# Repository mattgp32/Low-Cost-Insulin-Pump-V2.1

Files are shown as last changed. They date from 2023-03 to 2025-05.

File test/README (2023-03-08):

This directory is intended for PlatformIO Test Runner and project tests.

Unit Testing is a software testing method by which individual units of
source code, sets of one or more MCU program modules together with associated
control data, usage procedures, and operating procedures, are tested to
determine whether they are fit for use. Unit testing finds problems early
in the development cycle.

More information about PlatformIO Unit Testing:
- https://docs.platformio.org/en/latest/advanced/unit-testing/index.html

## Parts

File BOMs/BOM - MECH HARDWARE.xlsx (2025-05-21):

Value | Qty | Material | Unit Cost (USD) | Total Cost (USD) | Supplier
Lid | 1 | SLA (9600 Resin) | $1.0500 | $1.0500 | Digikey
Case | 1 | SLA (9600 Resin) | $0.3600 | $0.3600 | Digikey
Plunger | 1 | FDM (PLA) | $3.0000 | $3.0000 | Digikey
Threaded Insert | 1 | Aluminium | $0.0900 | $0.0900 | RS Components
M2 Bolt 20mm (for case) | 2 | Stainless Steel | $0.1000 | $0.2000 | Mecha4Makers
M2 Bolt 18mm (for PCB) | 1 | Aluminium | $0.1000 | $0.1000 | RS Components
 |  |  | TOTAL | $4.8000

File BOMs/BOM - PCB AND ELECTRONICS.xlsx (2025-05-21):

Reference | Value | Footprint | Qty | Unit Cost (USD) | Total Cost (USD) | Supplier | Supplier Part No.
BZ1 | Buzzer | Bluetooth Pump V2:ST-0503 BUZZER | 1 | $2.7900 | $2.7900 | Digikey | 433-1083-6-ND
C1 | 22uF | Capacitor_SMD:C_0402_1005Metric | 1 | $0.0800 | $0.0800 | Digikey | 587-1452-6-ND
C2,C4,C5,C13,C19 | 1uF | Capacitor_SMD:C_0402_1005Metric | 5 | $0.0800 | $0.4000 | Digikey | 587-1231-6-ND
C3,C9,C12,C20,C21,C22 | 100nF | Capacitor_SMD:C_0402_1005Metric | 6 | $0.1000 | $0.6000 | Digikey | 1276-CL05B104KP5VPNCDKR-ND
C6,C7 | 12pF | Capacitor_SMD:C_0402_1005Metric | 2 | $0.1500 | $0.3000 | Digikey | 490-11190-6-ND
C8 | 2.2uF | Capacitor_SMD:C_0402_1005Metric | 1 | $0.0800 | $0.0800 | Digikey | 1276-1469-6-ND
C10,C14,C15,C16,C24 | 10uF | Capacitor_SMD:C_0402_1005Metric | 5 | $0.0800 | $0.4000 | Digikey | 1276-1450-6-ND
C11,C28 | 100uF | Capacitor_SMD:C_1210_3225Metric | 2 | $0.5700 | $1.1400 | Digikey | 490-10530-6-ND
C17,C18 | 4.7uF | Capacitor_SMD:C_0402_1005Metric | 2 | $0.0800 | $0.1600 | Digikey | 1276-1481-6-ND
C25,C26,C27 | 10nF | Capacitor_SMD:C_0402_1005Metric | 3 | $0.1000 | $0.3000 | Digikey | 399-C0402C103K4REC7411DKR-ND
D1 | SD103AWS | Diode_SMD:D_SOD-323 | 1 | $0.1100 | $0.1100 | Digikey | 4530-SD103AWSDKR-ND
D2 | LED Green | LED_SMD:LED_0603_1608Metric | 1 | $0.1500 | $0.1500 | Digikey | 732-4980-6-ND
D3 | LED Red | LED_SMD:LED_0603_1608Metric | 1 | $0.1500 | $0.1500 | Digikey | 732-4978-6-ND
D5,D6,D7 | LED Blue | LED_SMD:LED_0603_1608Metric | 3 | $0.1500 | $0.4500 | Digikey | 732-4966-6-ND
FB1 | Ferrite Bead | Inductor_SMD:L_0402_1005Metric | 1 | $0.1600 | $0.1600 | Digikey | 3442-MZAH1005F101-1R1TFDKR-ND
J4 | GCT USB4085 | Connector_USB:USB_C_Receptacle_GCT_USB4085 | 1 | $0.8800 | $0.8800 | Digikey | 2073-USB4085-GF-ADKR-ND
J5 | Molex | Connector_Hirose:Hirose_DF13-04P-1.25DSA_1x04_P1.25mm_Vertical | 1 | $0.2700 | $0.2700 | Digikey | WM1733-ND
J6 | Conn_01x02 | Connector_PinHeader_1.27mm:PinHeader_1x02_P1.27mm_Vertical | 1 | $0.3900 | $0.3900 | Digikey | 455-1788-6-ND
J8,J9 | Thermistor | Connector_PinHeader_1.27mm:PinHeader_1x02_P1.27mm_Vertical | 2 | $0.5300 | $1.0600 | Digikey | 5666-103JG1J-ND
L1 | 4.7 uH | Inductor_SMD:L_1008_2520Metric | 1 | $0.1600 | $0.1600 | Digikey | 587-3228-6-ND
Q2 | MMBT2222A | Package_TO_SOT_SMD:SOT-23 | 1 | $0.4600 | $0.4600 | Digikey | 846-DTD543EE3TLDKR-ND
R1,R2,R8,R9,R10,R13,R21,R22,R29,R31 | 10K | Resistor_SMD:R_0402_1005Metric | 10 | $0.0390 | $0.3900 | Digikey | 1276-3431-6-ND
R3 | 180R | Resistor_SMD:R_0402_1005Metric | 1 | $0.1000 | $0.1000 | Digikey | A129618DKR-ND
R4,R5 | 0R | Resistor_SMD:R_0402_1005Metric | 2 | $0.1000 | $0.2000 | Digikey | P0.0JDKR-ND
R6,R7 | 5.11k | Resistor_SMD:R_0402_1005Metric | 2 | $0.1000 | $0.2000 | Digikey | 311-5.11KLRDKR-ND
R11,R12 | 500m | Resistor_SMD:R_0402_1005Metric | 2 | $0.2800 | $0.5600 | Digikey | 13-PT0402FR-070R5LDKR-ND
R16 | 130R | Resistor_SMD:R_0402_1005Metric | 1 | $0.1000 | $0.1000 | Digikey | RMCF0402FT130RDKR-ND
R17 | 1.43M | Resistor_SMD:R_0402_1005Metric | 1 | $0.1000 | $0.1000 | Digikey | 13-RC0402FR-071M43LDKR-ND
R18 | 360k | Resistor_SMD:R_0402_1005Metric | 1 | $0.1000 | $0.1000 | Digikey | 311-360KLRDKR-ND
R19 | 150R | Resistor_SMD:R_0402_1005Metric | 1 | $0.1000 | $0.1000 | Digikey | 311-150LRDKR-ND
R20 | 5K6 | Resistor_SMD:R_0402_1005Metric | 1 | $0.1000 | $0.1000 | Digikey | 311-5.6KLRDKR-ND
R24,R25 | 100K | Resistor_SMD:R_0402_1005Metric | 2 | $0.1000 | $0.2000 | Digikey | 311-100KJRDKR-ND
R26,R27,R28 | 50R | Resistor_SMD:R_0402_1005Metric | 3 | $0.1800 | $0.5400 | Digikey | 13-RT0402BRE0750RLDKR-ND
SW1 | RESET | Button_Switch_SMD:SW_DIP_SPSTx01_Slide_6.7x4.1mm_W6.73mm_P2.54mm_LowProfile_JPin | 1 | $0.2400 | $0.2400 | Digikey | CKN12330-6-ND
SW2 | BOOT | Button_Switch_SMD:SW_DIP_SPSTx01_Slide_6.7x4.1mm_W6.73mm_P2.54mm_LowProfile_JPin | 1 | $0.2400 | $0.2400 | Digikey | CKN12330-6-ND
SW3 | WIFI | Button_Switch_SMD:SW_DIP_SPSTx01_Slide_6.7x4.1mm_W6.73mm_P2.54mm_LowProfile_JPin | 1 | $0.2400 | $0.2400 | Digikey | CKN12330-6-ND
U1 | ESP32-S3-WROOM-1-N16R2 | GlucoseWatchFootprints:ESP32-S3-WROOM-1 | 1 | $6.1300 | $6.1300 | Digikey | 5407-ESP32-S3-WROOM-1-N16R2DKR-ND
U2 | RCLAMP1624T.TCT | GlucoseWatchFootprints:SLP1710P4T | 1 | $1.6800 | $1.6800 | Digikey | RCLAMP1624TTCTDKR-ND
U3 | DRV8846RGET | DRV8846RGET:QFN50P400X400X100-25N | 1 | $2.6600 | $2.6600 | Digikey | 296-40083-6-ND
U4 | ~ | Bluetooth Pump V2:DPAK | 1 | $0.9400 | $0.9400 | Digikey | AP7363-33D-13DKR-ND
U5 | MCP16414T-IMN | SOP50P490X110-10N:SOP50P490X110-10N | 1 | $0.8500 | $0.8500 | Digikey | 150-MCP16414T-I/UNDKR-ND
U6 | MCP73831-2-OT | Package_TO_SOT_SMD:SOT-23-5 | 1 | $0.7600 | $0.7600 | Digikey | MCP73831T-2DCI/OTDKR-ND
Y1 | FC-135_32.7680KA-A0 | FC-135_32.7680KA-A0:XTAL_FC-135_32.7680KA-A0 | 1 | $1.2400 | $1.2400 | Digikey | 535-13425-6-ND
Battery Connector | 02SR-3S | N/A | 1 | $0.2300 | $0.2300 | Digikey | 455-2183-ND
Slide Potentiometer | PTL20-15G1-203B2 | N/A | 1 | $2.4600 | $2.4600 | Digikey | PTL20-15G1-203B2-ND
Stepper Motor | CHS-GM12-10BY (Ratio 298:1, M4*55mm) | N/A | 1 | $9.9000 | $9.9000 | Alibaba | ChiHai Motor CHS-GM12-10BY
PCB Manufacture | JLCPCB | N/A | 1 | $0.7000 | $0.7000 | JLCPCB | N/A
LiPo-Battery | Emax 1S 3.8V 450mAh 80/160c HV | N/A | 1 | $8.3600 | $8.3600 | Hobby Station NZ | 1s45080c
 |  |  |  | TOTAL | $49.8100

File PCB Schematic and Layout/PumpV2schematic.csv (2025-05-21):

Reference | Value | Footprint | Datasheet | Qty | DNP | Exclude from BOM | Exclude from Board
5V1,BATT1,VBUS1 | TestPoint | TestPoint:TestPoint_Pad_1.0x1.0mm | ~ | 3
A1,A2,A3 | A0 | TestPoint:TestPoint_THTPad_1.0x1.0mm_Drill0.5mm | ~ | 3 |  | Excluded from BOM
BZ1 | Buzzer | Bluetooth Pump V2:ST-0503 BUZZER | ~ | 1
C1 | 22u | Capacitor_SMD:C_0402_1005Metric | https://www.digikey.co.nz/en/products/detail/samsung-electro-mechanics/CL05A226MQ5N6J8/7320595 | 1
C2,C4,C5,C13,C19 | 1uF | Capacitor_SMD:C_0402_1005Metric | https://www.digikey.co.nz/en/products/detail/tdk-corporation/C1005X5R1E105K050BC/3648556 | 5
C3,C9,C12,C20,C21,C22 | 100nF | Capacitor_SMD:C_0402_1005Metric | https://www.digikey.co.nz/en/products/detail/murata-electronics/GRM155C71H104JE19D/8323490,~ | 6
C6,C7 | 12pF | Capacitor_SMD:C_0402_1005Metric | ~ | 2
C8 | 2.2uF | Capacitor_SMD:C_0402_1005Metric | ~ | 1
C10,C14,C15,C16,C24 | 10uF | Capacitor_SMD:C_0402_1005Metric | ~ | 5
C11,C28 | 100uF | Capacitor_SMD:C_1210_3225Metric | ~ | 2
C17,C18 | 4.7uF | Capacitor_SMD:C_0402_1005Metric | ~ | 2
C25,C26,C27 | 10nF | Capacitor_SMD:C_0402_1005Metric | ~ | 3
D1 | SD103AWS | Diode_SMD:D_SOD-323 | ~ | 1
D2 | LED Green | LED_SMD:LED_0603_1608Metric | ~ | 1
D3 | LED Red | LED_SMD:LED_0603_1608Metric | ~ | 1
D5,D6,D7 | LED Blue | LED_SMD:LED_0603_1608Metric | ~ | 3
FB1 | Ferrite Bead | Inductor_SMD:L_0402_1005Metric | ~ | 1
H2 | MountingHole | MountingHole:MountingHole_2.2mm_M2_ISO7380_Pad_TopBottom | ~ | 1
J1 | Pot Connect | Connector_PinHeader_1.00mm:PinHeader_1x03_P1.00mm_Vertical | ~ | 1
J3 | GND TEST POINT | Connector_PinHeader_1.27mm:PinHeader_1x02_P1.27mm_Vertical | ~ | 1
J4 | GCT USB4085 | Connector_USB:USB_C_Receptacle_GCT_USB4085 | https://www.usb.org/sites/default/files/documents/usb_type-c.zip | 1
J5 | Molex | Connector_Hirose:Hirose_DF13-04P-1.25DSA_1x04_P1.25mm_Vertical | ~ | 1
J6 | Conn_01x02 | Connector_PinHeader_1.27mm:PinHeader_1x02_P1.27mm_Vertical | ~ | 1
J8,J9 | Thermistor | Connector_PinHeader_1.27mm:PinHeader_1x02_P1.27mm_Vertical | ~ | 2
L1 | 4.7 uH | Inductor_SMD:L_1008_2520Metric | ~ | 1
Q2 | MMBT2222A | Package_TO_SOT_SMD:SOT-23 | http://www.onsemi.com/pub_link/Collateral/2N2219-D.PDF | 1
R1 | 10k | Resistor_SMD:R_0402_1005Metric | ~ | 1
R2,R8,R9,R10,R13,R21,R22,R29,R31 | 10K | Resistor_SMD:R_0402_1005Metric | ~ | 9
R3 | 180R | Resistor_SMD:R_0402_1005Metric | ~ | 1
R4 | TBD | Resistor_SMD:R_0402_1005Metric | ~ | 1
R5 | TBD | Resistor_SMD:R_0402_1005Metric | ~ | 1 | DNP
R6,R7 | 5.11k | Resistor_SMD:R_0402_1005Metric | ~ | 2
R11,R12 | 500m | Resistor_SMD:R_0402_1005Metric | ~ | 2
R16 | 130R | Resistor_SMD:R_0402_1005Metric | ~ | 1
R17 | 1.43M | Resistor_SMD:R_0402_1005Metric | ~ | 1
R18 | 360k | Resistor_SMD:R_0402_1005Metric | ~ | 1
R19 | 150R | Resistor_SMD:R_0402_1005Metric | ~ | 1
R20 | 5K6 | Resistor_SMD:R_0402_1005Metric | ~ | 1
R24,R25 | 100K | Resistor_SMD:R_0402_1005Metric | ~ | 2
R26,R27,R28 | 50R | Resistor_SMD:R_0402_1005Metric | ~ | 3
SW1 | RESET | Button_Switch_SMD:SW_DIP_SPSTx01_Slide_6.7x4.1mm_W6.73mm_P2.54mm_LowProfile_JPin | ~ | 1
SW2 | BOOT | Button_Switch_SMD:SW_DIP_SPSTx01_Slide_6.7x4.1mm_W6.73mm_P2.54mm_LowProfile_JPin | ~ | 1
SW3 | WIFI | Button_Switch_SMD:SW_DIP_SPSTx01_Slide_6.7x4.1mm_W6.73mm_P2.54mm_LowProfile_JPin | ~ | 1
U1 | ESP32-S3-WROOM-1-N16R2 | GlucoseWatchFootprints:ESP32-S3-WROOM-1 | https://www.espressif.com/sites/default/files/documentation/esp32-s3-wroom-1_wroom-1u_datasheet_en.pdf | 1
U2 | RCLAMP1624T.TCT | GlucoseWatchFootprints:SLP1710P4T | https://semtech.my.salesforce.com/sfc/p/ | 1
U3 | DRV8846RGET | DRV8846RGET:QFN50P400X400X100-25N |  | 1
U4 | ~ | Bluetooth Pump V2:DPAK |  | 1
U5 | MCP16414T-IMN | SOP50P490X110-10N:SOP50P490X110-10N |  | 1
U6 | MCP73831-2-OT | Package_TO_SOT_SMD:SOT-23-5 | http://ww1.microchip.com/downloads/en/DeviceDoc/20001984g.pdf | 1
Y1 | FC-135_32.7680KA-A0 | FC-135_32.7680KA-A0:XTAL_FC-135_32.7680KA-A0 |  | 1

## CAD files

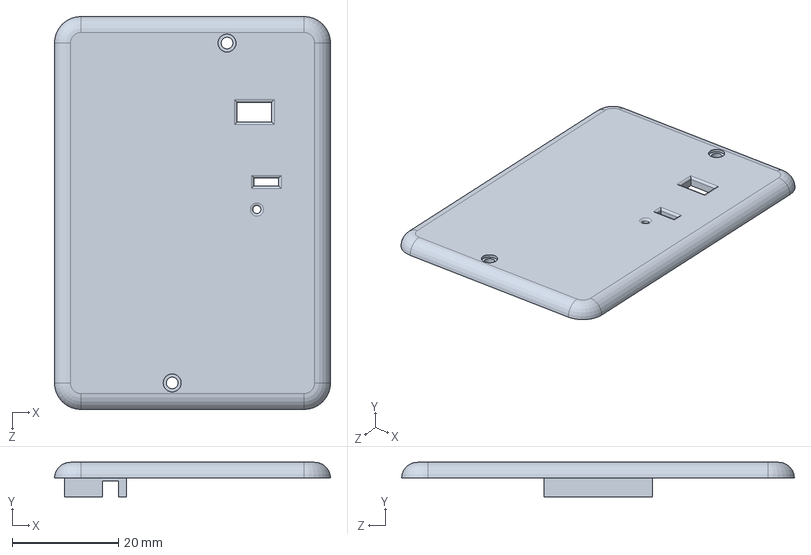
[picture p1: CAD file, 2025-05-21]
CAD Parts/SLDPRT/Lid redesignd.SLDPRT
52.0 x 6.50 x 74.0 mm

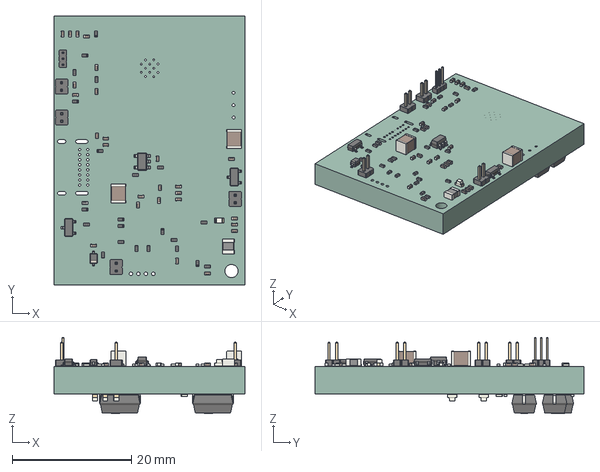
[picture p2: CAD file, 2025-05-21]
PCB Schematic and Layout/PumpV2schematic.step
32.0 x 45.0 x 12.8 mm
_autosave-PumpV2schematic PCB

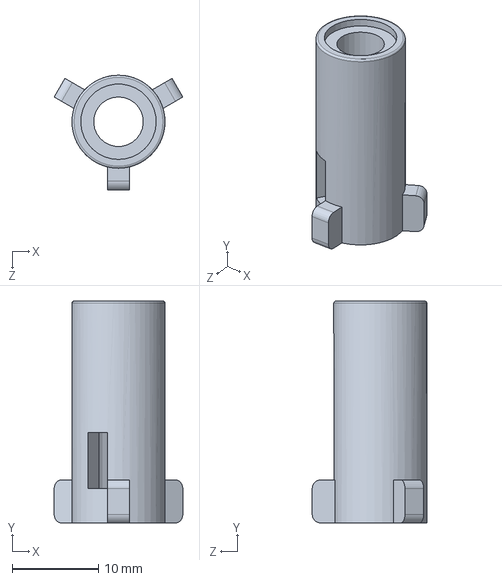
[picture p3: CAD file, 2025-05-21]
CAD Parts/SLDPRT/Plunger Extended.SLDPRT
14.9 x 25.8 x 13.3 mm

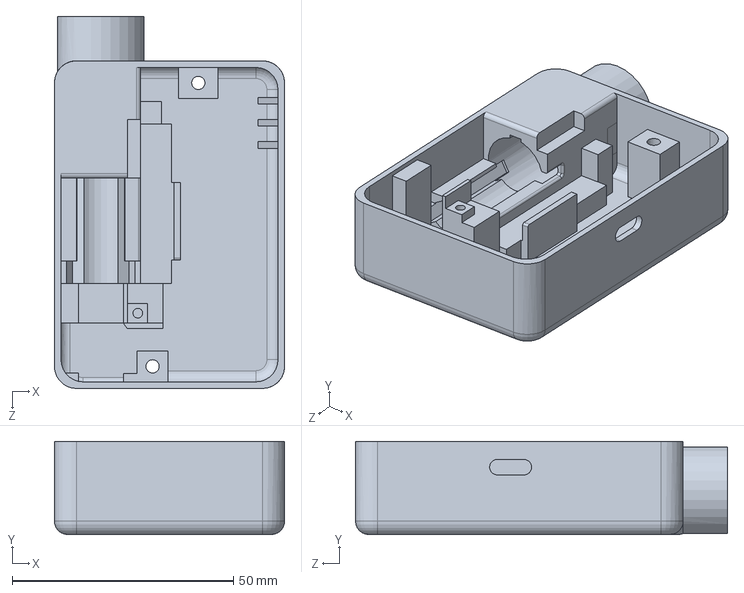
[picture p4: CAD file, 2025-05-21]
CAD Parts/SLDPRT/Case Redesign.SLDPRT
52.0 x 21.0 x 84.0 mm

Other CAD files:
CAD Parts/STL/Case Redesign.STL
CAD Parts/STL/Lid redesignd.STL

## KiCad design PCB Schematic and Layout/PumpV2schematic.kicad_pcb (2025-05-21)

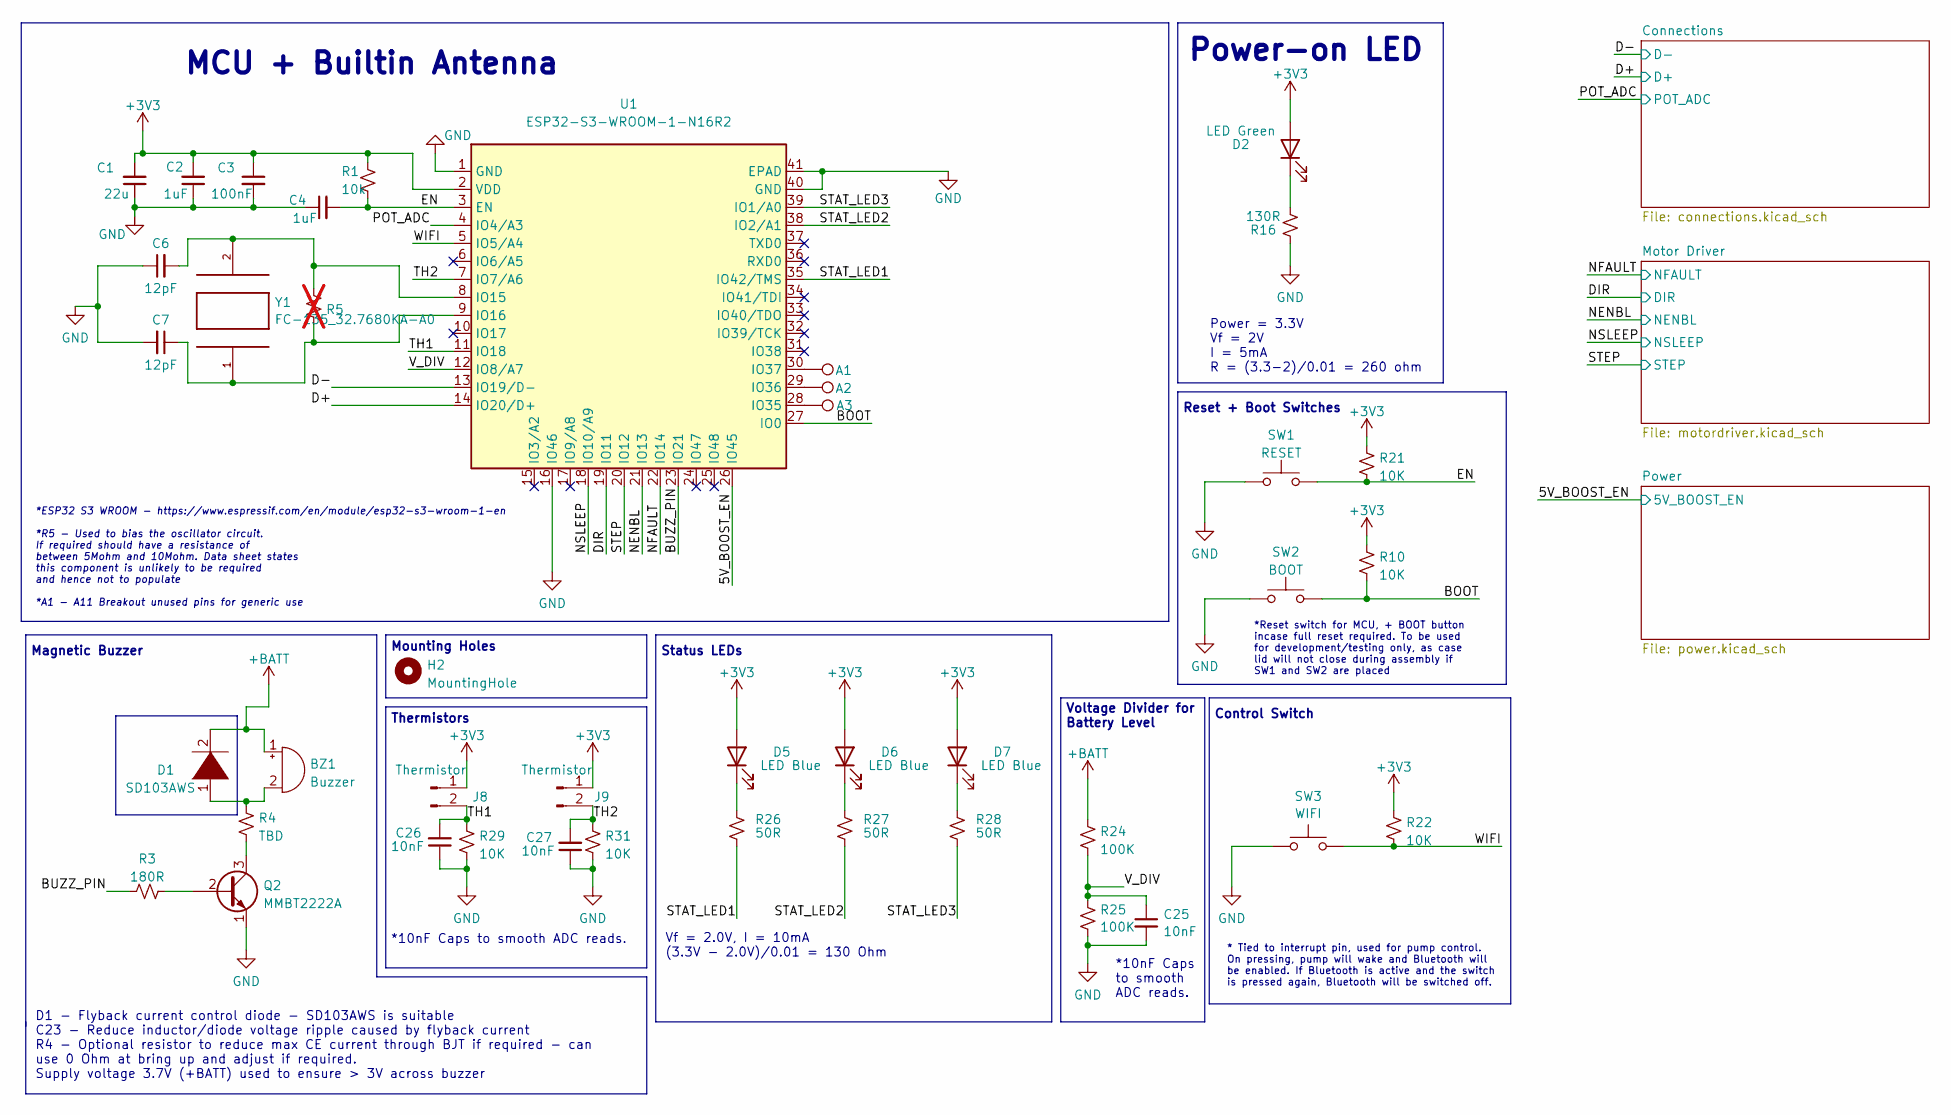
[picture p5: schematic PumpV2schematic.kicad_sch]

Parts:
A1, A2, A3: A0; TestPoint_THTPad_1.0x1.0mm_Drill0.5mm
BZ1: Buzzer; ST-0503 BUZZER
C1: 22u; C_0402_1005Metric; LCSC C2179118
C2, C4: 1uF; C_0402_1005Metric; LCSC C2887021
C3: 100nF; C_0402_1005Metric; LCSC C913614
C6, C7: 12pF; C_0402_1005Metric; LCSC C2235030
C25, C26, C27: 10nF; C_0402_1005Metric; LCSC C2167195
D1: SD103AWS; D_SOD-323; LCSC C181207
D2: LED Green; LED_0603_1608Metric; LCSC C84264
D5, D6, D7: LED Blue; LED_0603_1608Metric; LCSC C72041
H2: MountingHole; MountingHole_2.2mm_M2_ISO7380_Pad_TopBottom
J8, J9: Thermistor; PinHeader_1x02_P1.27mm_Vertical
Q2: MMBT2222A; SOT-23; LCSC C2891810
R1: 10k; R_0402_1005Metric; LCSC C25744
R3: 180R; R_0402_1005Metric; LCSC C911962
R4: TBD; R_0402_1005Metric; LCSC C17168
R5: TBD; R_0402_1005Metric; not fitted
R10, R21, R22, R29, R31: 10K; R_0402_1005Metric; LCSC C25744
R16: 130R; R_0402_1005Metric; LCSC C270649
R24, R25: 100K; R_0402_1005Metric; LCSC C319963
R26, R27, R28: 50R; R_0402_1005Metric; LCSC C477760
SW1: RESET; SW_DIP_SPSTx01_Slide_6.7x4.1mm_W6.73mm_P2.54mm_LowProfile_J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
SW2: BOOT; SW_DIP_SPSTx01_Slide_6.7x4.1mm_W6.73mm_P2.54mm_LowProfile_J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
SW3: WIFI; SW_DIP_SPSTx01_Slide_6.7x4.1mm_W6.73mm_P2.54mm_LowProfile_J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
U1: ESP32-S3-WROOM-1-N16R2; ESP32-S3-WROOM-1; LCSC C2913202
Y1: FC-135_32.7680KA-A0; XTAL_FC-135_32.7680KA-A0; LCSC C841881

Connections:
+3V3: C1.2, C2.2, C3.1, D2.2 (A), D5.2 (A), D6.2 (A), D7.2 (A), J8.1, J9.1, R1.1, R10.1, R21.1, R22.1, U1.2 (VDD); also elsewhere on the board
+BATT: BZ1.1 (-), D1.2 (A), R24.1; also elsewhere on the board
/5V_BOOST_EN: U1.26 (IO45); also elsewhere on the board
/BOOT: R10.2, SW2.2, U1.27 (IO0)
/BUZZ_PIN: R3.1, U1.23 (IO21)
/D+: U1.14 (IO20/D+); also elsewhere on the board
/D-: U1.13 (IO19/D-); also elsewhere on the board
/DIR: U1.19 (IO11); also elsewhere on the board
/EN: C4.2, R1.2, R21.2, SW1.2, U1.3 (EN)
/NENBL: U1.21 (IO13); also elsewhere on the board
/NFAULT: U1.22 (IO14); also elsewhere on the board
/NSLEEP: U1.18 (IO10/A9); also elsewhere on the board
/POT_ADC: U1.4 (IO4/A3); also elsewhere on the board
/STAT_LED1: R26.2, U1.35 (IO42/TMS)
/STAT_LED2: R27.2, U1.38 (IO2/A1)
/STAT_LED3: R28.2, U1.39 (IO1/A0)
/STEP: U1.20 (IO12); also elsewhere on the board
/TH1: C26.2, J8.2, R29.1, U1.11 (IO18)
/TH2: C27.2, J9.2, R31.1, U1.7 (IO7/A6)
/V_DIV: C25.1, R24.2, R25.1, U1.12 (IO8/A7)
/WIFI: R22.2, SW3.2, U1.5 (IO5/A4)
GND: C1.1, C2.1, C3.2, C4.1, C6.1, C7.2, C25.2, C26.1, C27.1, Q2.1 (E), R16.2, R25.2, R29.2, R31.2, SW1.1, SW2.1, SW3.1, U1.1 (GND), U1.16 (IO46), U1.40 (GND), U1.41 (EPAD); also elsewhere on the board
unnamed 24: BZ1.2 (+), D1.1 (K), R4.2; also elsewhere on the board
unnamed: D2.1 (K), R16.1
unnamed: D5.1 (K), R26.1
unnamed: D6.1 (K), R27.1
unnamed: D7.1 (K), R28.1
unnamed: Q2.2 (B), R3.2
unnamed: Q2.3 (C), R4.1
unnamed: C6.2, R5.1, U1.8 (IO15), Y1.2
unnamed: C7.1, R5.2, U1.9 (IO16), Y1.1
unnamed: A3.1, U1.28 (IO35)
unnamed: A2.1, U1.29 (IO36)
unnamed: A1.1, U1.30 (IO37)

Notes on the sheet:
Status LEDs
*10nF Caps to smooth ADC reads.
Magnetic Buzzer
Power = 3.3V Vf = 2V I = 5mA R = (3.3-2)/0.01 = 260 ohm
Reset + Boot Switches
*10nF Caps to smooth ADC reads.
MCU + Builtin Antenna
Thermistors
*ESP32 S3 WROOM - https://www.espressif.com/en/module/esp32-s3-wroom-1-en *R5 - Used to bias the oscillator circuit. If required should have a resistance of between 5Mohm and 10Mohm. Data sheet states this component is unlikely to be required and hence not to populate *A1 - A11 Breakout unused pins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
Vf = 2.0V, I = 10mA (3.3V - 2.0V)/0.01 = 130 Ohm
Voltage Divider for Battery Level
Power-on LED
* Tied to interrupt pin, used for pump control. On pressing, pump will wake and Bluetooth will be enabled. If Bluetooth is active and the switch is pressed again, Bluetooth will be switched off.
Control Switch
*Reset switch for MCU, + BOOT button incase full reset required. To be used for development/testing only, as case lid will not close during assembly if SW1 and SW2 are placed
Mounting Holes
D1 - Flyback current control diode - SD103AWS is suitable C23 - Reduce inductor/diode voltage ripple caused by flyback current R4 - Optional resistor to reduce max CE current through BJT if required - can use 0 Ohm at bring up and adjust if required. Supply voltage 3.7V (+BATT) used to ensure > 3V 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

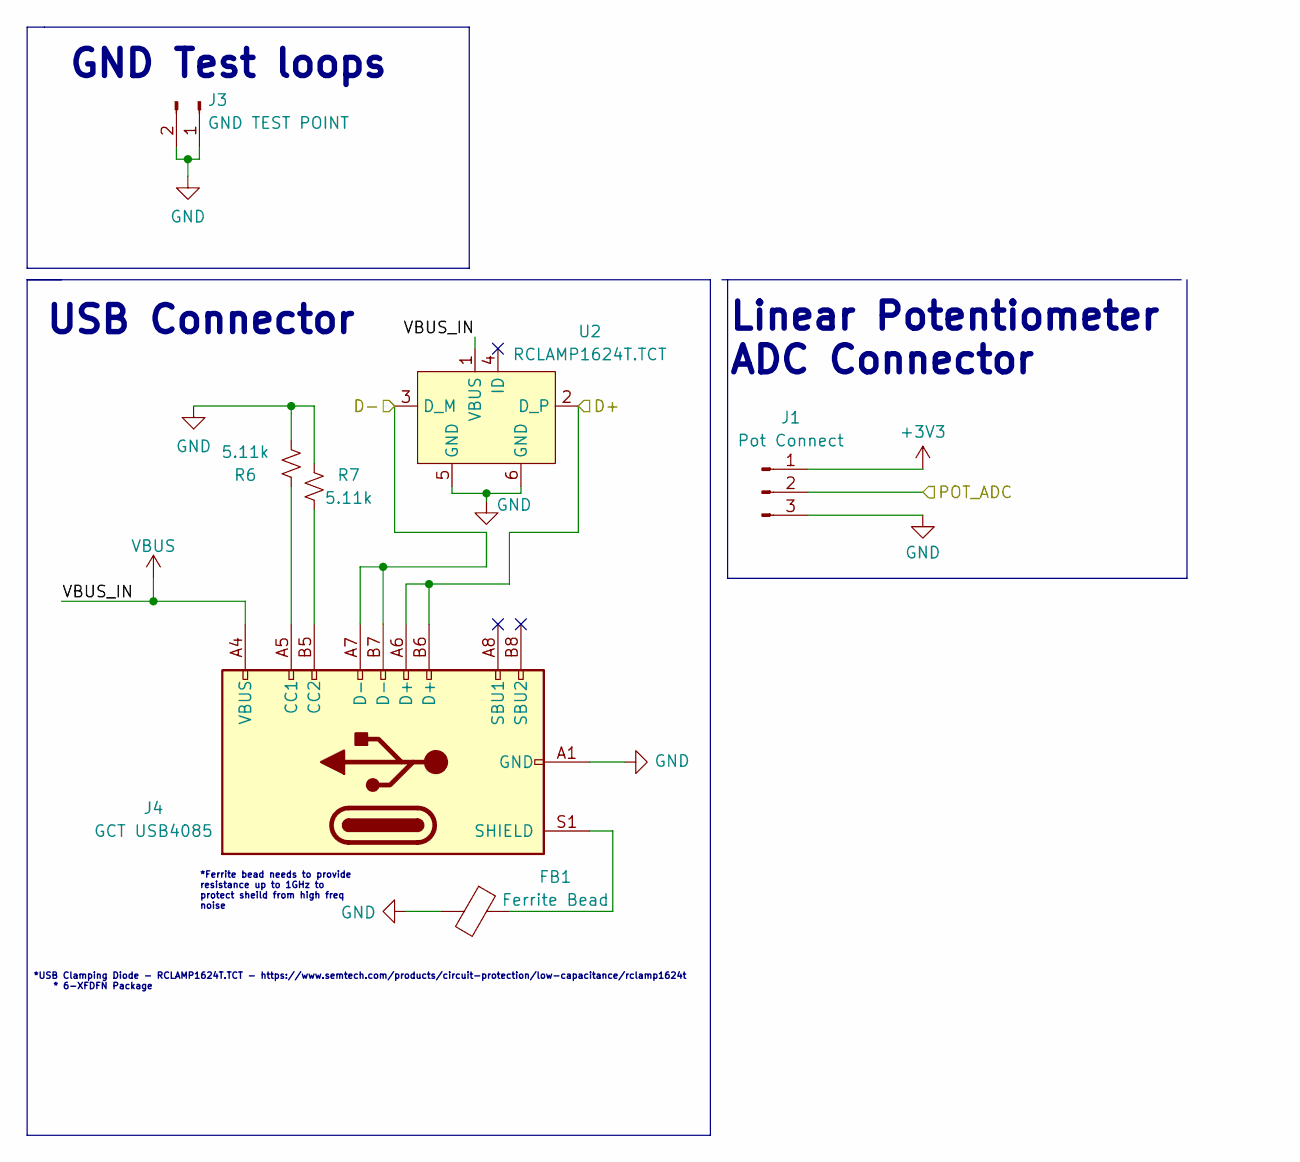
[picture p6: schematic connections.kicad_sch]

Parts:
FB1: Ferrite Bead; L_0402_1005Metric; LCSC C21516
J1: Pot Connect; PinHeader_1x03_P1.00mm_Vertical
J3: GND TEST POINT; PinHeader_1x02_P1.27mm_Vertical
J4: GCT USB4085; USB_C_Receptacle_GCT_USB4085
R6: 5.11k; R_0402_1005Metric; LCSC C310235
R7: 5.11k; R_0402_1005Metric
U2: RCLAMP1624T.TCT; SLP1710P4T; LCSC C1973485

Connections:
+3V3: J1.1; also elsewhere on the board
/D+: J4.A6 (D+), J4.B6 (D+), U2.2 (D_P); also elsewhere on the board
/D-: J4.A7 (D-), J4.B7 (D-), U2.3 (D_M); also elsewhere on the board
/POT_ADC: J1.2; also elsewhere on the board
GND: FB1.2, J1.3, J3.1, J3.2, J4.A1 (GND), J4.A12 (GND), J4.B1 (GND), J4.B12 (GND), R6.2, R7.2, U2.5 (GND), U2.6 (GND); also elsewhere on the board
unnamed: J4.A5 (CC1), R6.1
unnamed: J4.B5 (CC2), R7.1
unnamed: FB1.1, J4.S1 (SHIELD)
VBUS: J4.A4 (VBUS), J4.A9 (VBUS), J4.B4 (VBUS), J4.B9 (VBUS), U2.1 (VBUS); also elsewhere on the board

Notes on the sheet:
Linear Potentiometer ADC Connector
*USB Clamping Diode - RCLAMP1624T.TCT - https://www.semtech.com/products/circuit-protection/low-capacitance/rclamp1624t * 6-XFDFN Package
*Ferrite bead needs to provide resistance up to 1GHz to protect sheild from high freq noise
USB Connector
GND Test loops

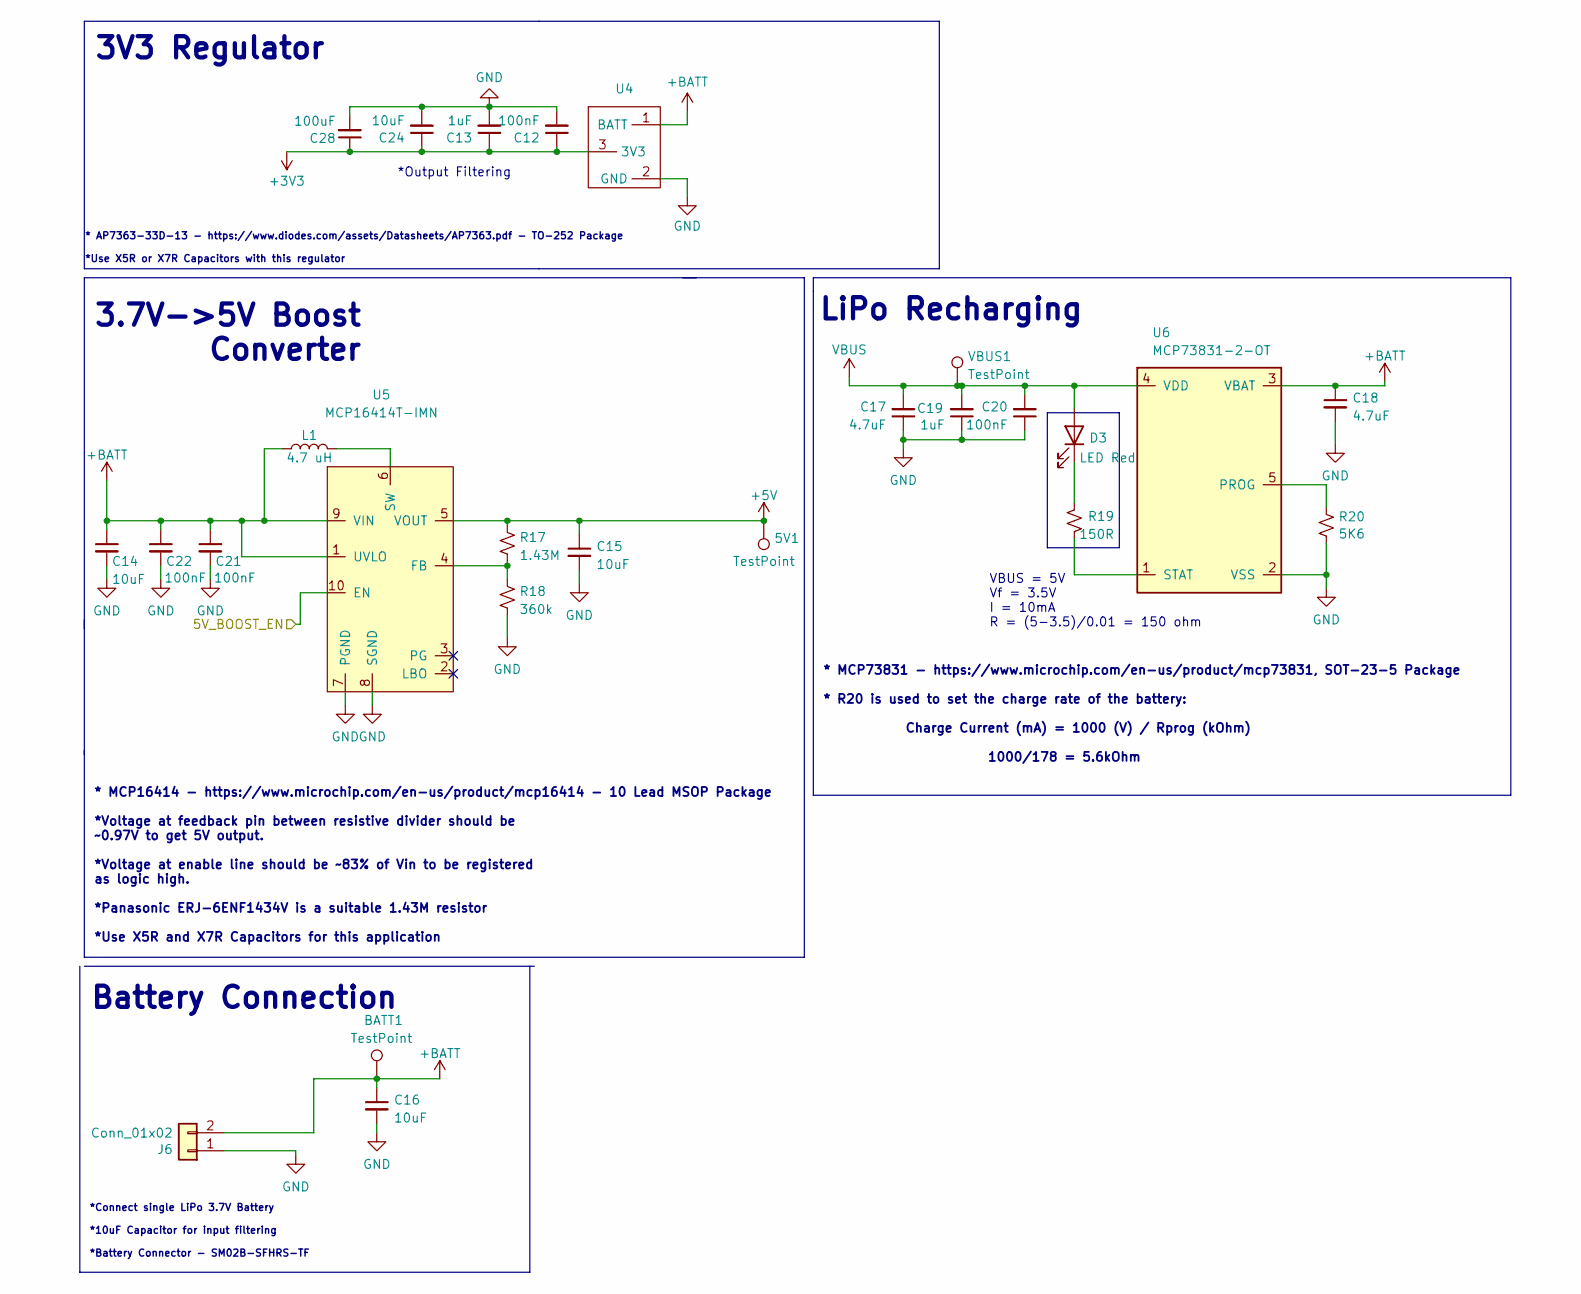
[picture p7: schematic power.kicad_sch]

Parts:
5V1: TestPoint; TestPoint_Pad_1.0x1.0mm
BATT1: TestPoint; TestPoint_Pad_1.0x1.0mm
C12, C20, C21, C22: 100nF; C_0402_1005Metric; LCSC C913614
C13, C19: 1uF; C_0402_1005Metric; LCSC C2887021
C14, C15, C16, C24: 10uF; C_0402_1005Metric; LCSC C1864622
C17, C18: 4.7uF; C_0402_1005Metric; LCSC C723999
C28: 100uF; C_1210_3225Metric; LCSC C2762605
D3: LED Red; LED_0603_1608Metric; LCSC C2286
J6: Conn_01x02; PinHeader_1x02_P1.27mm_Vertical
L1: 4.7 uH; L_1008_2520Metric; LCSC C2981204
R17: 1.43M; R_0402_1005Metric; LCSC C368342
R18: 360k; R_0402_1005Metric; LCSC C413117
R19: 150R; R_0402_1005Metric; LCSC C3015763
R20: 5K6; R_0402_1005Metric; LCSC C174239
U4: DPAK; LCSC C108723
U5: MCP16414T-IMN; SOP50P490X110-10N; LCSC C1518054
U6: MCP73831-2-OT; SOT-23-5; LCSC C625597
VBUS1: TestPoint; TestPoint_Pad_1.0x1.0mm

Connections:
+3V3: C12.1, C13.1, C24.1, C28.1, U4.3 (3V3); also elsewhere on the board
+5V: 5V1.1, C15.1, R17.1, U5.5 (VOUT); also elsewhere on the board
+BATT: BATT1.1, C14.1, C16.1, C18.1, C21.1, C22.1, J6.2, L1.1, U4.1 (BATT), U5.1 (UVLO), U5.9 (VIN), U6.3 (VBAT); also elsewhere on the board
/5V_BOOST_EN: U5.10 (EN); also elsewhere on the board
GND: C12.2, C13.2, C14.2, C15.2, C16.2, C17.1, C18.2, C19.1, C20.1, C21.2, C22.2, C24.2, C28.2, J6.1, R18.2, R20.2, U4.2 (GND), U5.7 (PGND), U5.8 (SGND), U6.2 (VSS); also elsewhere on the board
unnamed: D3.1 (K), R19.2
unnamed: R17.2, R18.1, U5.4 (FB)
unnamed: L1.2, U5.6 (SW)
unnamed: R20.1, U6.5 (PROG)
unnamed: R19.1, U6.1 (STAT)
VBUS: C17.2, C19.2, C20.2, D3.2 (A), U6.4 (VDD), VBUS1.1; also elsewhere on the board

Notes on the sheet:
* MCP73831 - https://www.microchip.com/en-us/product/mcp73831, SOT-23-5 Package * R20 is used to set the charge rate of the battery: Charge Current (mA) = 1000 (V) / Rprog (kOhm) 1000/178 = 5.6kOhm
* MCP16414 - https://www.microchip.com/en-us/product/mcp16414 - 10 Lead MSOP Package *Voltage at feedback pin between resistive divider should be ~0.97V to get 5V output. *Voltage at enable line should be ~83% of Vin to be registered as logic high. *Panasonic ERJ-6ENF1434V is a suitable 1.43M resis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
3V3 Regulator
LiPo Recharging
3.7V->5V Boost Converter
* AP7363-33D-13 - https://www.diodes.com/assets/Datasheets/AP7363.pdf - TO-252 Package *Use X5R or X7R Capacitors with this regulator
Battery Connection
*Output Filtering
*Connect single LiPo 3.7V Battery *10uF Capacitor for input filtering *Battery Connector - SM02B-SFHRS-TF
VBUS = 5V Vf = 3.5V I = 10mA R = (5-3.5)/0.01 = 150 ohm

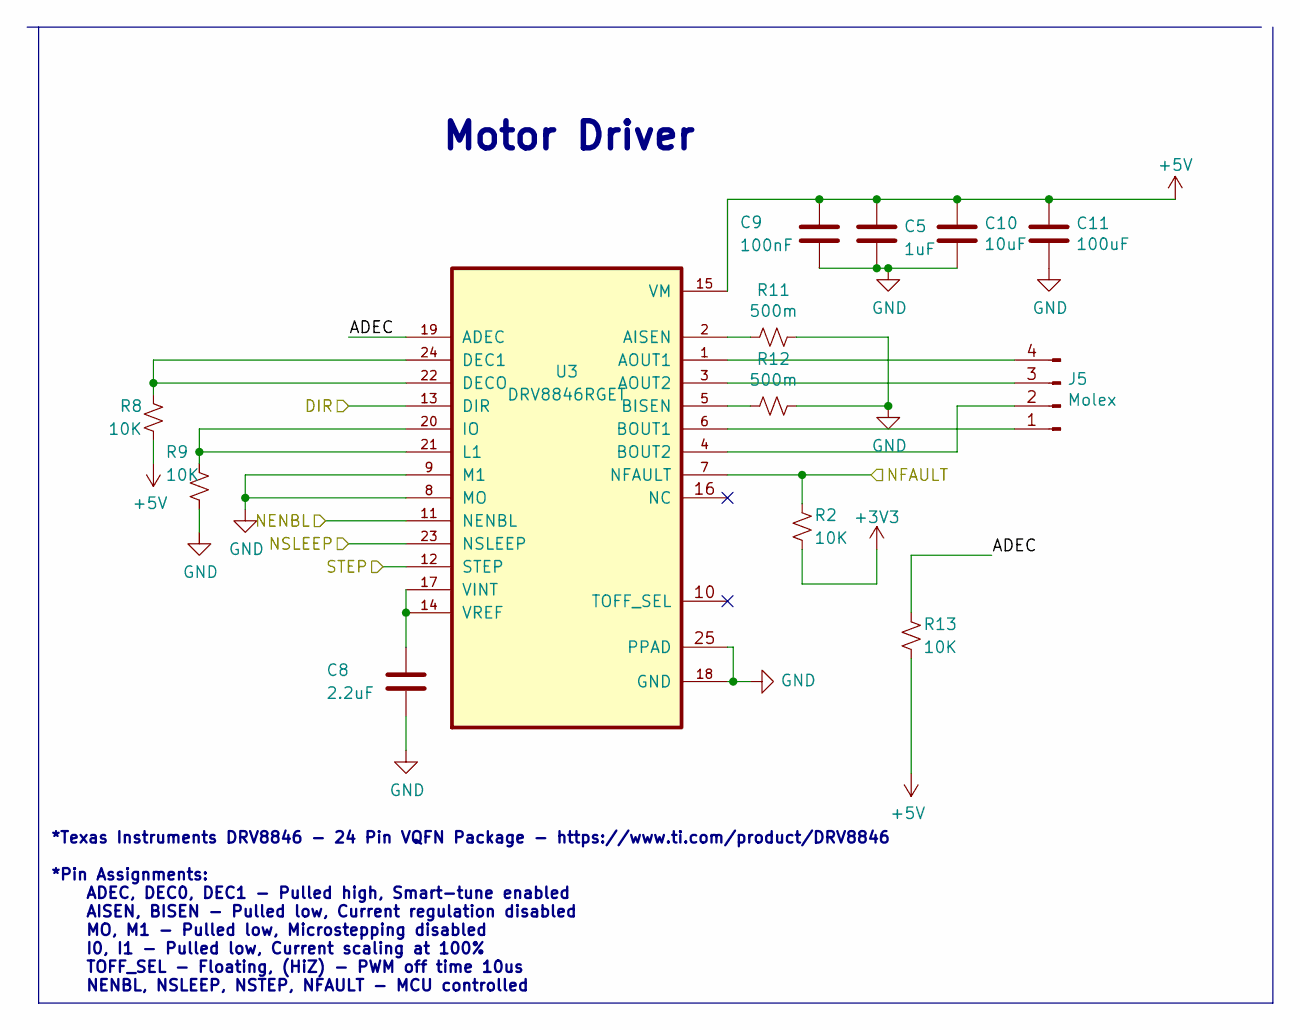
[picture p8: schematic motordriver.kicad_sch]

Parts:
C5: 1uF; C_0402_1005Metric; LCSC C2887021
C8: 2.2uF; C_0402_1005Metric; LCSC C710862
C9: 100nF; C_0402_1005Metric; LCSC C913614
C10: 10uF; C_0402_1005Metric; LCSC C1864622
C11: 100uF; C_1210_3225Metric; LCSC C2762605
J5: Molex; Hirose_DF13-04P-1.25DSA_1x04_P1.25mm_Vertical
R2, R8, R9, R13: 10K; R_0402_1005Metric; LCSC C25744
R11, R12: 500m; R_0402_1005Metric; LCSC C5204041
U3: DRV8846RGET; QFN50P400X400X100-25N; LCSC C473340

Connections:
+3V3: R2.2; also elsewhere on the board
+5V: C5.1, C9.1, C10.1, C11.1, R8.2, R13.2, U3.15 (VM); also elsewhere on the board
/DIR: U3.13 (DIR); also elsewhere on the board
/Motor Driver/ADEC: R13.1, U3.19 (ADEC)
/NENBL: U3.11 (NENBL); also elsewhere on the board
/NFAULT: R2.1, U3.7 (NFAULT); also elsewhere on the board
/NSLEEP: U3.23 (NSLEEP); also elsewhere on the board
/STEP: U3.12 (STEP); also elsewhere on the board
GND: C5.2, C8.2, C9.2, C10.2, C11.2, R9.2, R11.1, R12.1, U3.8 (MO), U3.9 (M1), U3.18 (GND), U3.25 (PPAD); also elsewhere on the board
unnamed: J5.1, U3.6 (BOUT1)
unnamed: J5.2, U3.4 (BOUT2)
unnamed: J5.3, U3.3 (AOUT2)
unnamed: J5.4, U3.1 (AOUT1)
unnamed: R11.2, U3.2 (AISEN)
unnamed: R12.2, U3.5 (BISEN)
unnamed: R8.1, U3.22 (DECO), U3.24 (DEC1)
unnamed: R9.1, U3.20 (IO), U3.21 (L1)
unnamed: C8.1, U3.14 (VREF), U3.17 (VINT)

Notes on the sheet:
Motor Driver
*Texas Instruments DRV8846 - 24 Pin VQFN Package - https://www.ti.com/product/DRV8846 *Pin Assignments: ADEC, DEC0, DEC1 - Pulled high, Smart-tune enabled AISEN, BISEN - Pulled low, Current regulation disabled MO, M1 - Pulled low, Microstepping disabled I0, I1 - Pulled low, Current scaling at 100% 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

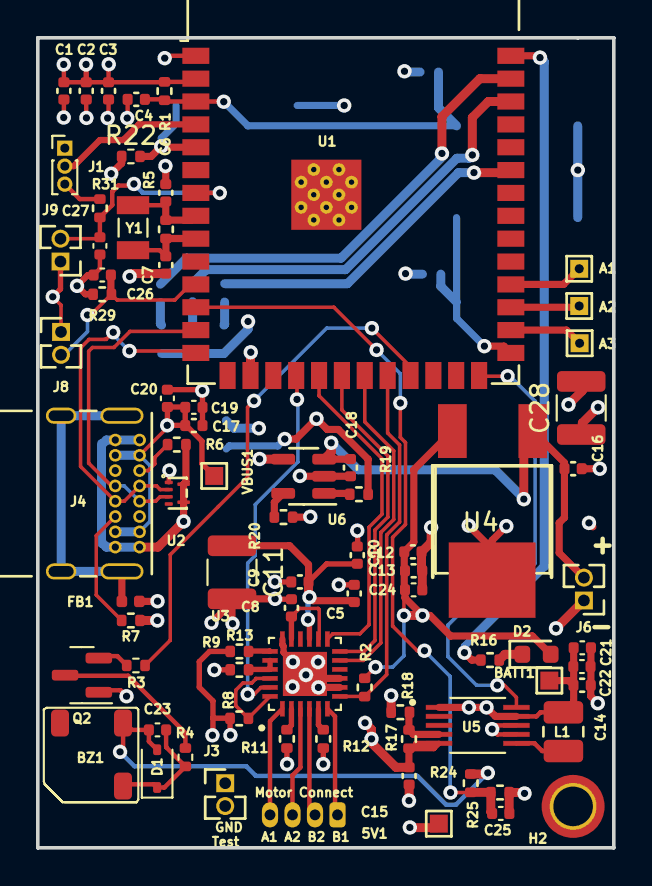
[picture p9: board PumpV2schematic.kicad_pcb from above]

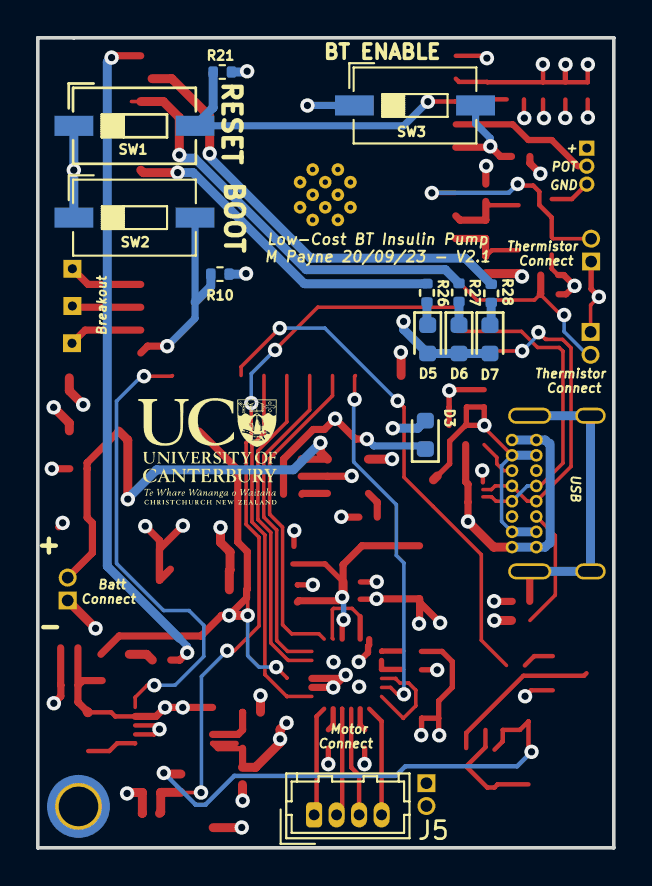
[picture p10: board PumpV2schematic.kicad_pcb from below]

Board: 4 copper layers, 32.0 x 45.0 mm, 89 parts (13 on the bottom side), 54 nets.

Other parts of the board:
C23: 1uF; C_0402_1005Metric

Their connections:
+BATT: C23.1; also elsewhere on the board
unnamed 24: C23.2; also elsewhere on the board

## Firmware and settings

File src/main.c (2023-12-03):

#include "rtc_mgp.h"
#include <inttypes.h>
#include "freertos/FreeRTOS.h"
#include "freertos/task.h"
#include "freertos/queue.h" 
#include "freertos/timers.h"
#include "freertos/event_groups.h"
#include "freertos/semphr.h"
#include "motor.h"
#include "ble_comp_test.h"
#include "adc.h"
#include "leds.h"
#include "stdio.h"
#include "pump_BT.h"
#include <assert.h>
#include "nvs_flash.h"
#include "esp_bt.h"
#include "esp_err.h"
#include "esp_pm.h"
#include "esp_log.h"
#include "ins_rate.h"
#include "esp_gap_ble_api.h"
#include "esp_gatts_api.h"
#include "esp_bt_defs.h"
#include "esp_bt_main.h"
#include "driver/gptimer.h"
#include "esp_pm.h"
#include "driver/gpio.H"
#include "esp_private/esp_clk.h"

#define POT_POWER GPIO_NUM_37
extern bool enable_BT;

void IRAM_ATTR gpio_isr_handler(void *args)
    {
    enable_BT = true;
    puts("interrupt worked");
    }


void app_main(void)
{
//Initialise system peripherals to be used after freeRTOS starts
    esp_pm_config_esp32s3_t pm_config = {
            .max_freq_mhz = 80,
            .min_freq_mhz = 40,
    };
    ESP_ERROR_CHECK( esp_pm_configure(&pm_config) );
    // small delay might be necessary for the frequency setting to take effect — the idle task should have a chance to run
    vTaskDelay(pdMS_TO_TICKS(10));
    // now the frequency should be 40 MHz
    assert(esp_clk_cpu_freq() == 80 * 1000000);

    init_leds();
    //buzzer_init();
    run_BT();
    init_motor();

    gpio_set_intr_type(GPIO_NUM_41, GPIO_INTR_POSEDGE);
    gpio_install_isr_service(0);
    gpio_isr_handler_add(GPIO_NUM_41, gpio_isr_handler, (void *)GPIO_NUM_41);

   

    // gpio_set_direction(GPIO_NUM_42, GPIO_MODE_INPUT);
    // gpio_pulldown_en(GPIO_NUM_42);
    // gpio_pullup_dis(GPIO_NUM_42);
    // gpio_intr_enable(GPIO_NUM_42);

    // Create all tasks for the freeRTOS scheduler
    // xTaskCreate(sleep_for_20, "Puts MCU to sleep for 20s", 2048,NULL, 10, NULL);
    xTaskCreate(get_batt_level, "Read ADC and write batt level to a queue", 1024, NULL, 5, NULL);
    xTaskCreate(display_batt_level, "Blink LED depending on batt level", 8192, NULL, 5, NULL);
    xTaskCreate(receive_BT_data, "get data from bt buffer",8192, NULL, 10, NULL);
    xTaskCreate(process_bt_data, "print data from bt buffer",8192, NULL, 10, NULL);
    xTaskCreate(retreive_data, "Display rate data - for debugging only", 8192, NULL, 5, NULL);
    xTaskCreate(no_br_warning, "flash led if br = 0", 2048, NULL, 5, NULL);
    xTaskCreate(give_insulin, "start insulin deliveries", 4096, NULL, 20, NULL);
    xTaskCreate(bolus_delivery, "give bolus", 4092, NULL, 21, NULL);
    xTaskCreate(read_pot, "potentimoeter read", 4092, NULL, 5, NULL);
    xTaskCreate(rewind_plunge, "rewind motor if flag set", 4092, NULL, 4, NULL);
    // xTaskCreate(BT_off, "turn off BT", 4092, NULL, 4, NULL);
    // xTaskCreate(BT_Control_Task, "BT_Control_Task", 2048, NULL, 1, NULL);
}

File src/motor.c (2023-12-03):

/*  **** Module written by Matt Payne as part of UC Summer Scholarship 2019 - 2020 for the insulin pump project.
    **** Started on 22/11/2019
	**** Modified for BT Insulin Pump Project on 7/3/23
    **** This module contains a collection of functions to be used to drive the motor in the pump to deliver insulin.
*/

// define forward and backward directions and a variable to track how many steps the motor has turned.

#include "stdint.h"
#include <stdbool.h>
#include "stdio.h"
#include "driver/gpio.h"
#include "freertos/FreeRTOS.h"
#include "freertos/task.h"
#include "rom/ets_sys.h"


#define nFAULT GPIO_NUM_14
#define DIR GPIO_NUM_11
#define STEP GPIO_NUM_12
#define BOOST_EN GPIO_NUM_45
#define MOTOR_DRIVER_ENABLE GPIO_NUM_13
#define nSLEEP GPIO_NUM_10

#define FORWARD 0
#define BACKWARD 1
#define DELAY_TIME 500

uint32_t steps_turned = 0;

void init_motor()
// Initialise all the pins required to allow the motor to be driven
{
    gpio_set_direction(nFAULT, GPIO_MODE_INPUT);
    gpio_set_direction(DIR, GPIO_MODE_OUTPUT);
    gpio_set_direction(STEP, GPIO_MODE_OUTPUT);
    gpio_set_direction(BOOST_EN, GPIO_MODE_OUTPUT);
    gpio_set_direction(MOTOR_DRIVER_ENABLE, GPIO_MODE_OUTPUT);
	gpio_set_direction(nSLEEP, GPIO_MODE_OUTPUT);
    gpio_set_level(MOTOR_DRIVER_ENABLE, true);
}

void enable_motor()
{
	gpio_set_level(BOOST_EN, true);
    gpio_set_level(MOTOR_DRIVER_ENABLE, false);
	gpio_set_level(nSLEEP, true);
	vTaskDelay(200/portTICK_PERIOD_MS);
}

void disable_motor()
{
	gpio_set_level(BOOST_EN, false);
    gpio_set_level(MOTOR_DRIVER_ENABLE, true);
	gpio_set_level(nSLEEP, false);
	vTaskDelay(200/portTICK_PERIOD_MS);
}

bool read_motor_fault_pin()
// read the status of the motor fault pin. Return false if there is a fault with the motor and a true if all is good.
{
	bool fault_pin = gpio_get_level(nFAULT);
	return fault_pin;
}

void set_motor_direction(bool direction)
// call this function to change the value of the DIR pin on the IC which controls the direction the motor turns
{
	gpio_set_level(DIR, direction);
}


void step_motor(bool direction)
/* this function will call set_motor_direction() to set the motor function to turn one step in the direction of the passed variable. If there is a falult with the motor nothing will happen.
   One step will then be recorded in the steps_turned variable to keep track of how much the motor has turned */
{
		set_motor_direction(direction);
		gpio_set_level(STEP, 1);
		ets_delay_us(800);
		gpio_set_level(STEP, 0);
		ets_delay_us(800);
		steps_turned += 1;
	
	
}

void turn_x_steps(bool direction, uint16_t steps_to_turn)
/* this function will turn the motor x number of steps in the specified direction. x will have to be worked out from the basal rate, bolus rate, and motor testing to determine
   how much insulin is actually required */ 
{
	enable_motor();

	while(steps_to_turn > 0)
	{
		step_motor(direction);
		steps_to_turn -=1;
	}

	disable_motor();
}

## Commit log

2023-04-18 pump has both basal and bolus functionality now
2023-05-01 pump has basal and bolus functionaity, connects to app and gives feedback throiugh LED flashes
2023-07-18 WIP Commit - Updating to Standardised Structure and Repeatable Build ENV
    [partitions.csv]
2023-11-15 Undo Accidental Merge
    [partitions.csv]
2025-01-13 Add aia file for insulin pump app
2025-05-21 Added BOMs for electrical and mechanical hardware
    [BOM - MECH HARDWARE.xlsx, BOM - PCB AND ELECTRONICS.xlsx]
2025-05-21 Add BOM files, and mech and PCB hardware files
    [BOM - MECH HARDWARE.xlsx, BOM - PCB AND ELECTRONICS.xlsx, Case Redesign.SLDPRT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]
